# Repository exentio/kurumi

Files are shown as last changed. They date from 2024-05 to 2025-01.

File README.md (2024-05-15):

# Kurumi

Addressable LED strip controller, based on the ESP32-C3 SuperMini.  
This is a shrinkage of a previous private project that was quite janky due to
my friend's needs.

**WARNING: the buck converter is currently not working properly.**

Designed to run at 5V or any voltage between 12V and 24V.  
In case of 5V strips, the buck converter part won't need to be populated;
instead, short jumper JP1's central pin to VCC.  
**DON'T DO THIS FOR ANY VOLTAGE OVER 5V OR YOU WILL FRY YOUR ESP32.**  

For strips running at 12V or more, short JP1 to INT (internal converter).  
**The buck converter is not designed for voltages over 24V.**  

The data pin is connected to GPIO5, at the moment no ESPhome or WLED
configuration has been made, you'll have to spin your own until I get the board
and test everything.  

The board also supports using relays or MOSFETs to cut power to the strip by
using the broken out pins J3. The EN pin is connected to GPIO4 and can be used
to control the switching device. Don't forget to short JP2 as needed, whether
you want to switch the power or not.  

It's recommended to add insulation over the jumpers and on unpopulated pads on
the bottom if the buck converter is not used (i.e. electrical or kapton tape).  

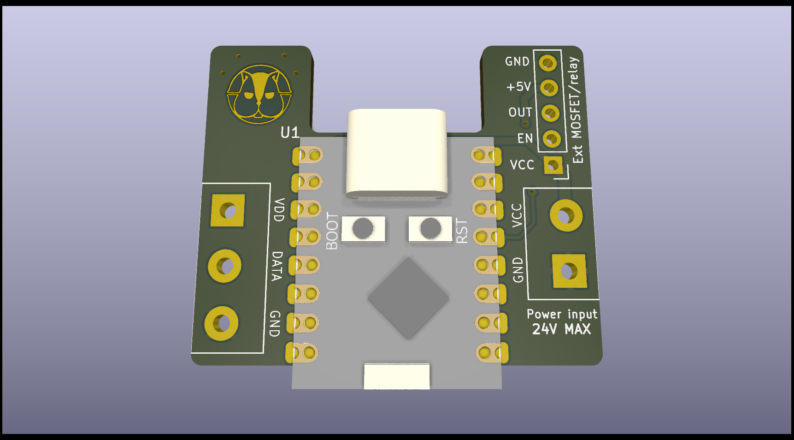
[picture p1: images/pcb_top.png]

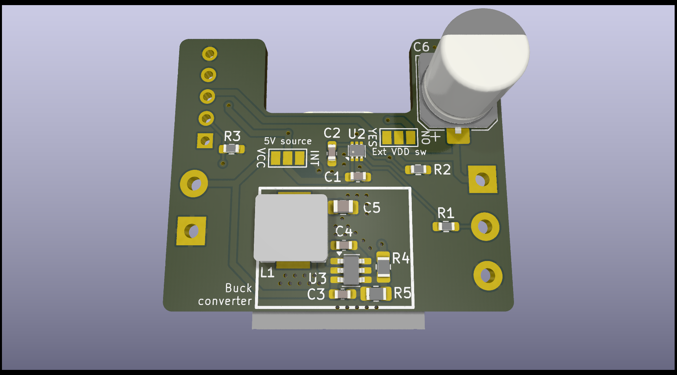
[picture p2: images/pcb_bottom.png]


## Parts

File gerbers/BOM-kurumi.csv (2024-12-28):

Comment | Designator | Footprint | LCSC | Quantity
100nF | C4 | C_0603_1608Metric_Pad1.08x0.95mm_HandSolder | C1591 | 1
1uF | C1,C2 | C_0603_1608Metric_Pad1.08x0.95mm_HandSolder | C1592 | 2
TPS54308 | U3 | SOT-23-6_Handsoldering | C168839 | 1
100K | R4 | R_0805_2012Metric_Pad1.20x1.40mm_HandSolder | C1859593 | 1
2.2uF | C3 | C_0603_1608Metric_Pad1.08x0.95mm_HandSolder | C307463 | 1
13.7K | R5 | R_0805_2012Metric_Pad1.20x1.40mm_HandSolder | C317432 | 1
33uF | C5 | C_0805_2012Metric_Pad1.18x1.45mm_HandSolder | C342635 | 1
SN74LVC1T45DRL | U2 | SOT-563 | C352970 | 1
470 | R1 | R_0603_1608Metric_Pad0.98x0.95mm_HandSolder | C491208 | 1
10uH | L1 | CYA0630 | C5189958 | 1
470uF | C6 | CP_Elec_8x10.5 | C7471889 | 1
4.7K | R2,R3 | R_0603_1608Metric_Pad0.98x0.95mm_HandSolder | C844791 | 2

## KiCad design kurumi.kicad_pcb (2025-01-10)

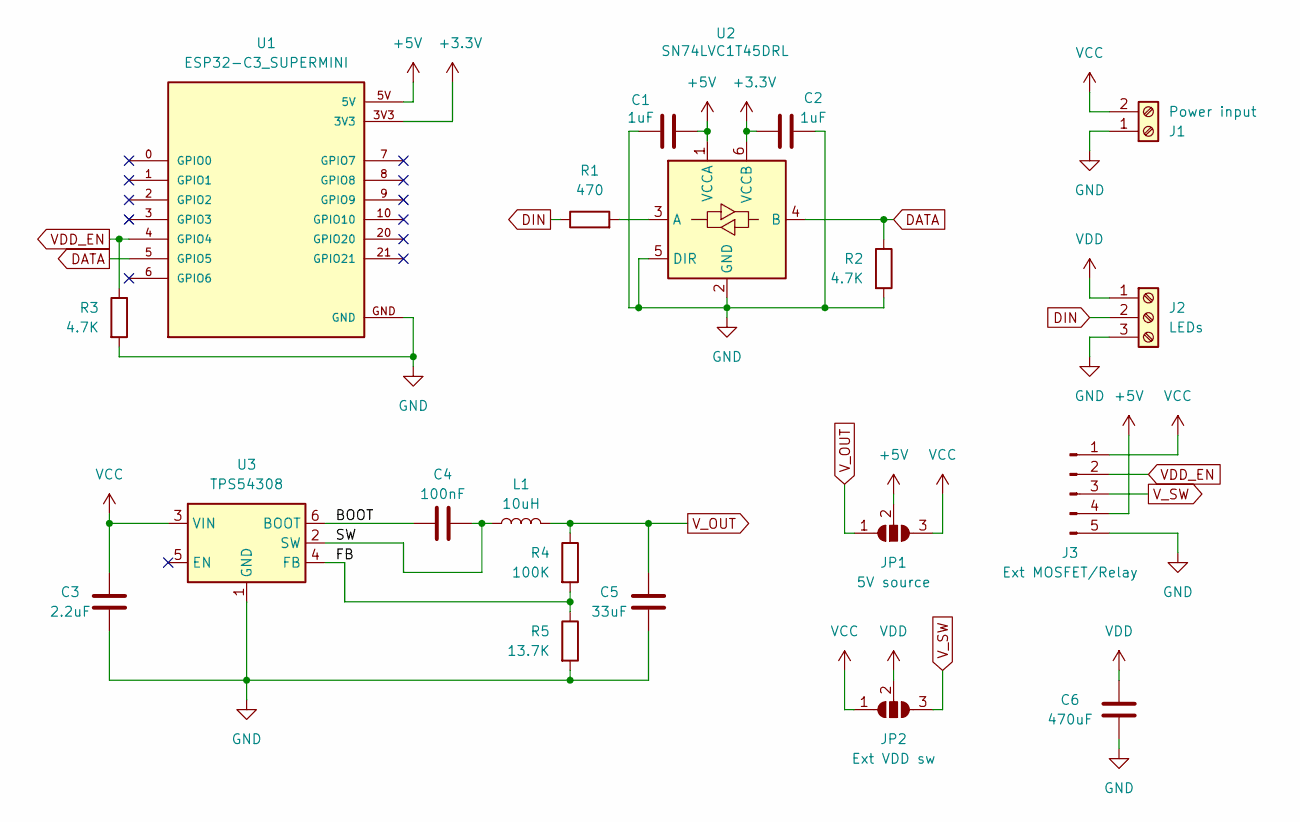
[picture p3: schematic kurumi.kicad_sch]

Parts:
C1, C2: 1uF; C_0603_1608Metric_Pad1.08x0.95mm_HandSolder
C3: 2.2uF; C_0603_1608Metric_Pad1.08x0.95mm_HandSolder
C4: 100nF; C_0603_1608Metric_Pad1.08x0.95mm_HandSolder
C5: 33uF; C_0805_2012Metric_Pad1.18x1.45mm_HandSolder
C6: 470uF; CP_Elec_8x10.5
J1: Power input; TerminalBlock_bornier-2_P5.08mm
J2: LEDs; TerminalBlock_bornier-3_P5.08mm
J3: Ext MOSFET/Relay; PinHeader_1x05_P2.54mm_Vertical
JP1: 5V source; SolderJumper-3_P1.3mm_Open_Pad1.0x1.5mm_NumberLabels
JP2: Ext VDD sw; SolderJumper-3_P1.3mm_Open_Pad1.0x1.5mm_NumberLabels
L1: 10uH; CYA0630
R1: 470; R_0603_1608Metric_Pad0.98x0.95mm_HandSolder
R2, R3: 4.7K; R_0603_1608Metric_Pad0.98x0.95mm_HandSolder
R4: 100K; R_0805_2012Metric_Pad1.20x1.40mm_HandSolder
R5: 13.7K; R_0805_2012Metric_Pad1.20x1.40mm_HandSolder
U1: ESP32-C3_SUPERMINI; MODULE_ESP32-C3_SUPERMINI_CASTELLATED
U2: SN74LVC1T45DRL; SOT-563
U3: TPS54308; SOT-23-6_Handsoldering

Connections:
+3.3V: C2.2, U1.3V3, U2.6 (VCCB)
+5V: C1.1, J3.4, JP1.2 (C), U1.5V, U2.1 (VCCA)
/BOOT: C4.2, U3.6 (BOOT)
/FB: R4.2, R5.1, U3.4 (FB)
/SW: C4.1, L1.1, U3.2 (SW)
DATA: R2.1, U1.5 (GPIO5), U2.4 (B)
DIN: J2.2, R1.1
GND: C1.2, C2.1, C3.2, C5.2, C6.2, J1.1, J2.3, J3.5, R2.2, R3.2, R5.2, U1.GND, U2.2 (GND), U2.5 (DIR), U3.1 (GND)
unnamed: R1.2, U2.3 (A)
VCC: C3.1, J1.2, J3.1, JP1.3 (B), JP2.1 (A), U3.3 (VIN)
VDD: C6.1, J2.1, JP2.2 (C)
VDD_EN: J3.2, R3.1, U1.4 (GPIO4)
V_OUT: C5.1, JP1.1 (A), L1.2, R4.1
V_SW: J3.3, JP2.3 (B)

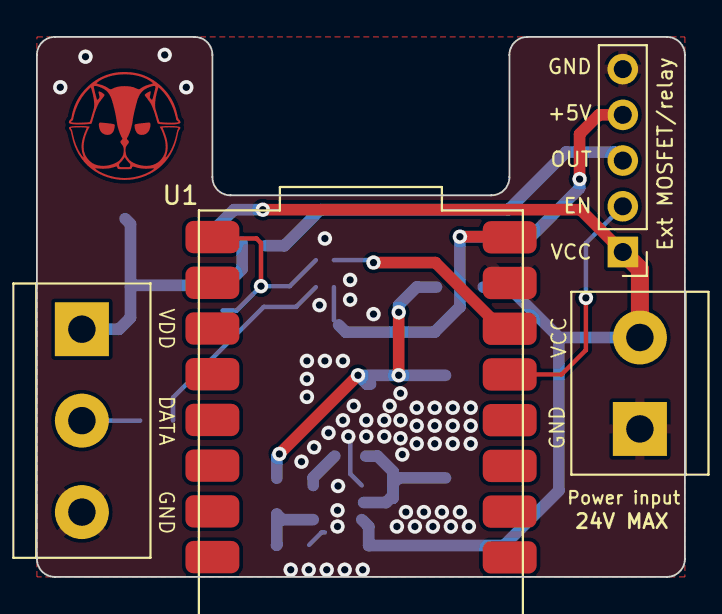
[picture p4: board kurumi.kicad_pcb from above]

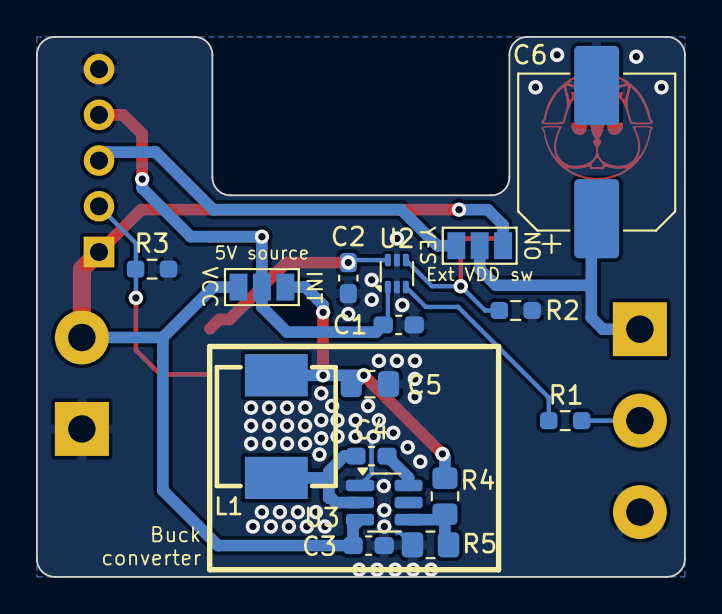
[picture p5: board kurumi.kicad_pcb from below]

Board: 2 copper layers, 36.0 x 30.0 mm, 20 parts (16 on the bottom side), 14 nets.

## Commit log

2024-03-27 Footprint and readme update
    [kurumi.kicad_pcb]
2024-03-27 Added libraries
    [kurumi.kicad_pcb]
2024-03-27 Gerbers update
    [kurumi-B_Cu.gbl, kurumi-B_Mask.gbs, kurumi-B_Paste.gbp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]
2024-03-27 Parts updates, BOM and CPL
    [BOM-kurumi.csv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]
2024-05-15 Minor changes
    [kurumi.kicad_pcb, kurumi.kicad_sch]
2024-05-15 Addes USB slot, fixed libraries
    [kurumi.kicad_pcb]
2024-06-19 Buck converter fix by @CRImier
    [BOM-kurumi.csv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]
2024-07-21 Gerbers and JLCPCB files update
    [BOM-kurumi.csv, BOM_kurumi.csv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]
2024-07-22 BOM and CPL update
    [BOM-kurumi.csv, BOM_kurumi.csv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]
2024-12-28 Fix JLCPCB rotations
    [BOM-kurumi.csv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]
2025-01-10 Broken out 5V for relays and more
    [kurumi.kicad_pcb, kurumi.kicad_sch]
2025-01-10 Readme images update
    [kurumi.kicad_pcb]
